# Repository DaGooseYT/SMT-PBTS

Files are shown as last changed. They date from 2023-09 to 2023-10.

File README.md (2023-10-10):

# Surface Mount Technology - Portable Bluetooth Speaker (SMT-PBTS)

<p align="center">
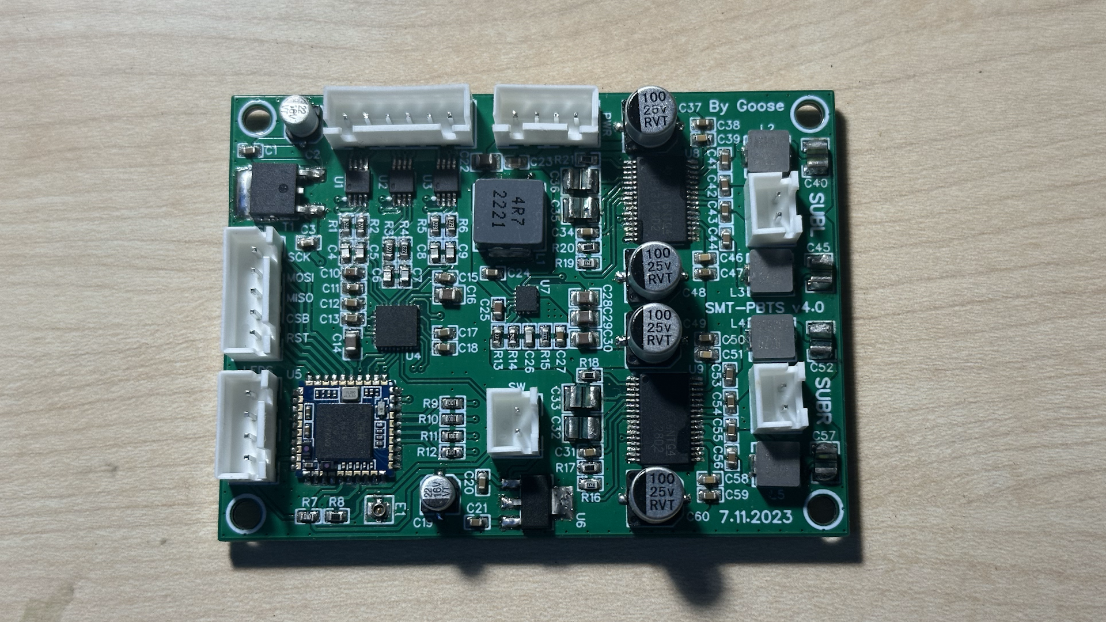
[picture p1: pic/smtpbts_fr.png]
  
</p>

SMT-PBTS is an open source, Hi-Fi Bluetooth speaker PCB designed for the smallest, best sounding portable Bluetooth speaker applications. Just smaller than a credit card, it features multi-channel configurations for an immersive soundstage, a programmable audio DSP, Bluetooth v5.0 technology with external antenna support, 24-bit 192kHz audio support and more.

## Key Features

- Ultra small and compact design; just smaller than a credit card.
- Bluetooth v5.0 specification via Qualcomm’s CSR8675 SoC.
- Connect up to 2 devices simultaneously for shared musical playback.
- Up to 300ft theoretical Bluetooth connectivity range using external antenna.
- Supports nearly every Bluetooth A2DP streaming codec: AAC, SBC, MP3, aptX Classic, aptX-LL, aptX-HD, Faststream  
- High fidelity audio playback with up to 24-bits and 192kHz sample rate support (only using aptX-HD codec).
- Incredible frequency response; 40Hz-22KHz @-3dB (only with suggested drivers and enclosure).
- High efficiency eliminates the need for heatsinks.
- Hybrid amplifier design consisting of Class D amplifiers for the bass drivers and linear Class AB amplifiers for the left, right, and center tweeters.
- Ultra low total harmonic distortion, even at maximum power: ~0.03% THD.
- Ultra low signal to noise ratio: > 108dB
- 35W + 35W onboard Class D amplifiers with 3x1W Class AB amplifiers.
- Uses high-end Panasonic acrylic resin film caps for all audio decoupling filters.

## Schematic

The schematic source for this project is located in `/src`. It is released as an EasyEDA source file. The PNG of the schematic is located in `/pic`.

## PCB

PCB sources are located in `/src`. The sources are EasyEDA PCB design filetypes. PCB gerbers are in the releases.

## BoM
- BoM is available as a .csv file in `/main`
- Only parts and components on the PCB are in the BoM.

## Suggested Enclosure Design

- Outer enclosure demensions are as follows (in): Length: 10.5; Width: 4.25; Depth: 3.5
- Speaker hole diameters (in): Left and right surround speakers: 1.9; two bass drivers: 3.5; center speaker: 1.9
- Connector, Port, and LED hole diameters (in): Power & AUX connectors: 0.5; LEDs: 3/16; Port: 5/8
- It is recommended to use polyfill in the enclosure for better frequency response and dampening. 
- The port of the enslosure is a PVC pipe with a inner diameter of 0.6 inches and is 9.75 inches in length (port tuning is between 40Hz - 45Hz).
- 0.25in thick MDF wood is reccomended for the speaker enclosure build.

## Suggested Drivers

- The two bass drivers are 3.5in in diameter and are manufactured by BH Acoustics (see [datasheet](https://cdn.komachine.com/media/product-catalog/bh-acoustic_84067_fngrun.pdf)). They were salvaged from two Samsung WAM1500 smart speakers. Due two the limited availability of these drivers, it is recomended to use [these drivers](https://www.parts-express.com/dayton-audio-nd90-4-3-1-2-aluminum-cone-full-range-neo-driver-4-ohm--290-208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) as an alternative.
- The center driver is a tweeter. It is rated at 10w 4ohm and was also pulled from a Samsung WAM1500. There is no other public documentation of this driver. [This](https://www.amazon.com/dp/B00LSEVA8I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) driver can be used instead. 
- The two surround tweeters can be found [here](https://a.co/d/8RPXRJ0).

## I/O Connectors
- Power input via 5.5mm power jack. Buy it [here](https://www.parts-express.com/21-x-55mm-dc-coaxial-power-snap-in-jack--090-5030)
- This PCB features Bluetooth v5.0 using the BTM875-E Bluetooth module. The module can be reprogrammed to change the device's name as well as other properties. The programmer module is required because you need to flash the custom firmware onto the chip, which contains the code to drive the AIC3254 slave device. Buy [this](https://www.digikey.com/short/0d7541zq) programmer.

## Other PCB Dependant Componants
- The pre-modulated 4s BMS PCB can be found [here](https://a.co/d/1r3xPFF). I highly suggest swapping out the main IC on this BMS with [this](https://mou.sr/46K4Cju) one for better discharge/overcharge protection and best compatibility with SMT-PBTS.
- Samsung 50E 21700 battery cells can be found [here](https://www.18650batterystore.com/products/samsung-50e) (order 4 for 14.4V configuration)
- Buy lithium-ion battery nickel strips [here](https://a.co/d/34JzgvJ)
- To prevent fire, use 20AWG wires or better for the power connections and TPA3128D2 output connections.
- 16.8V 2A lithium ion battery charger can be found [here](https://a.co/d/1eIaQfp)

## Licensing
This repo is licensed under the GPL v3.0. Any images are licensed under CC BY-SA 3.0.

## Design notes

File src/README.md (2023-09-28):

# Custom firmware configuration guide
SMT-PBTS uses Qualcomm's CSR8675 via the BTM875-E module for Bluetooth radio music streaming. SMT-PBTS requires a specific firmware configuration in order for everything to function as expected. The default firmware I configured myself for my specific application is in the releases. However, your application will be slightly different and therefore it is highly recommended to create your own firmware for the best quality results. This guide will show you the general steps for the correct custom firmware configuration.

## Requirements
- [This](https://www.digikey.com/short/0d7541zq) USB-SPI programmer
- Texas Instruments [PurePath Studio](https://www.ti.com/tool/AICPUREPATH_STUDIO) (proprietary, requires registration)
- CSR867X ADK v4.3.1.5 - software development kit (proprietary, you must find on your own)
- Knowledge of the C programming language
- Knowledge of Qualcomm's xIDE and standard library (I won't discuss its usage in this guide, please read its docs)
- Knowledge of the I2C bus protocol

## Configuring PurePath code
<p align="center">
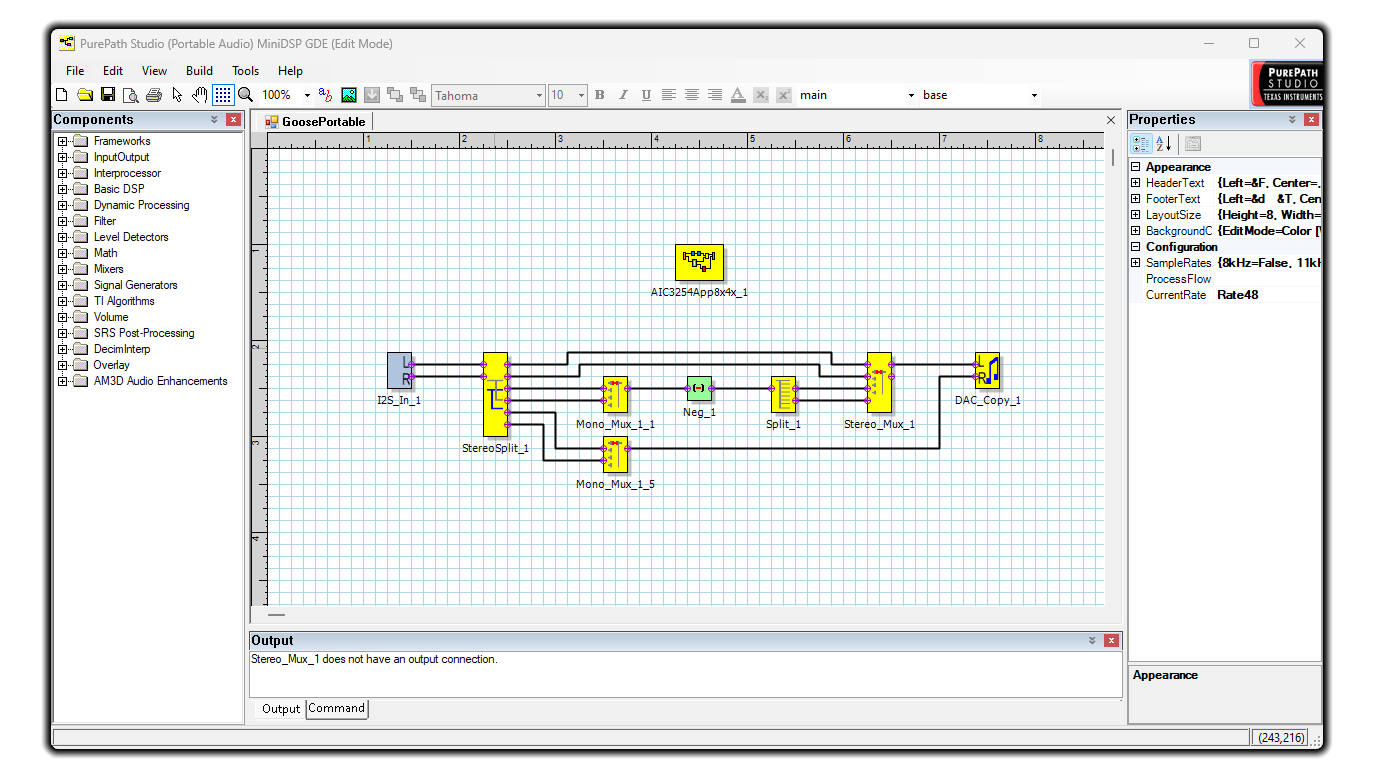
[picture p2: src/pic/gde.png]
  
</p>

Use GDE in the PurePath portable installation to configure the AIC3254 to your liking. The photo above is the configuration used in the firmware I have configured for my specific application. Be sure to use I2S as the input and set the PLL clock to BCLK (this can be found in the AIC3254 app configuration block). The left output channel is for the surround tweeters and the right output is for the center tweeter.

<p align="center">
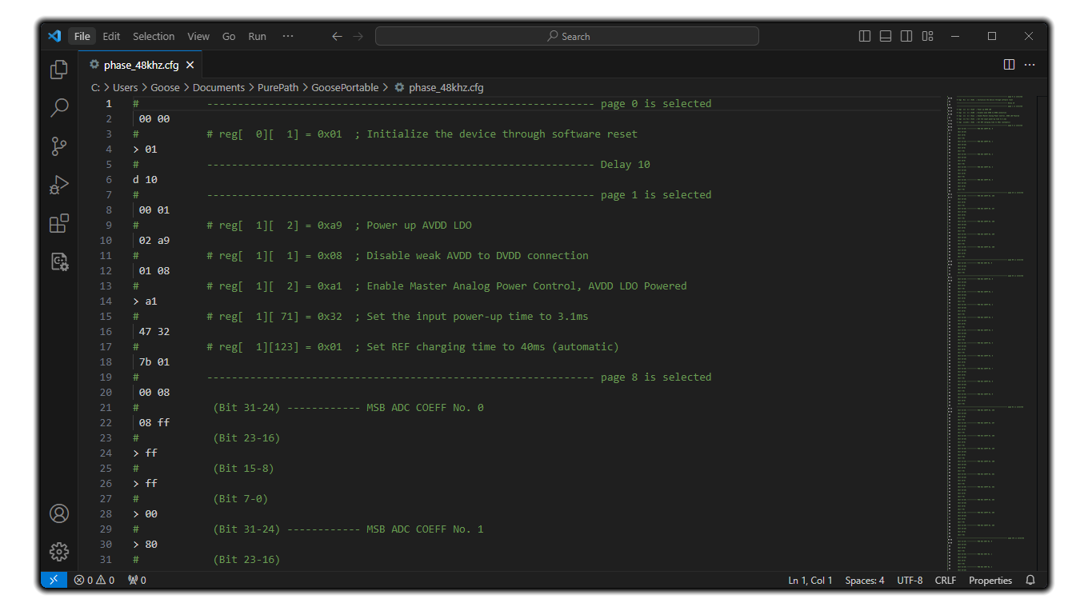
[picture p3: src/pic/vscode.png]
  
</p>

Above is the assembled output code from the GDE configuration. This code must be tweaked in order to be compatible with the CSR8675 firmware that we will build soon. The code lines starting with 'd' must be removed entirely. Delay is not supported in the CSR8675 firmware. The '>' ressembles register incrementation from the previous line which is also not supported and so you must convert these to register values in hex too.

## Adding code to the sink application

<p align="center">
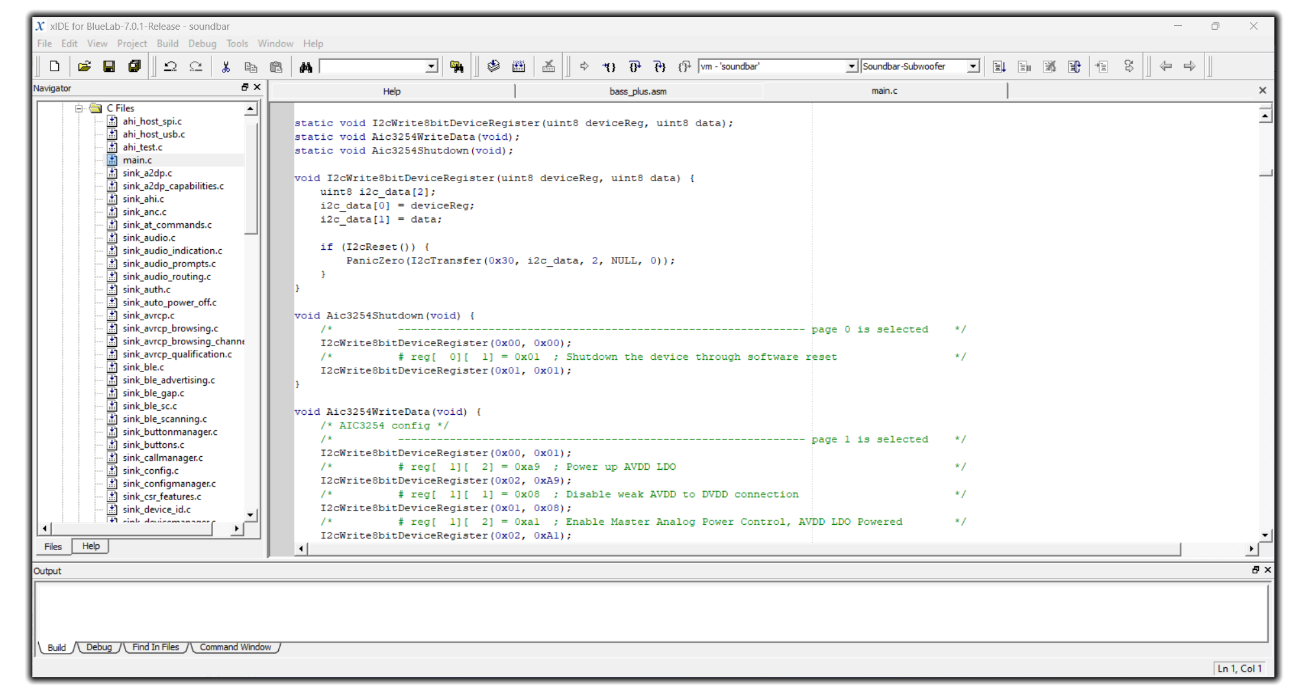
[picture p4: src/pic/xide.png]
  
</p>

Open xIDE in the ADK v4.3.1.5 installation folder and use one of the sample sink app workspaces in the `/apps` directory as a template for your firmware (I recommend the `soundbar.xiw` sample). Also add any of the decoders that you would like (AAC, MP3, aptX-HD, etc.) by going to `Project > Insert project to workspace` and selecting the kalimba project files (in `/a2dp_sink` directory) relating to the codecs that you would like configured.<br />
Create functions and add the code assembled from PurePath GDE into the `main.c` file in the `vm - soundbar` xIDE project. See the `main.c` file in this repository's `/src` folder for a complete example. The example file has the I2C library functions set up and demonstrates the function usage for all relevant code.<br />
Finally, change the configuration properties of the `vm - soundbar` project so that the device is set to CSR8675, the transfer is SPI, and wired audio is enabled (for I2S). You can configure other properties such as subwoofer link, hi-res audio output and more there too, but is completely optional. Be aware though that the CSR8675 on the BTM875-E module only has 16MB of flash memory. Make sure you don't have everything enabled in the project properties as the device will not have enough storage for all of the features! Open the `speaker.mak` file in the `vm -speaker` project and uncomment the A2DP decoder compilation paths for the decoders that you have added to the workspace. 

## Flashing the CSR8675

<p align="center">
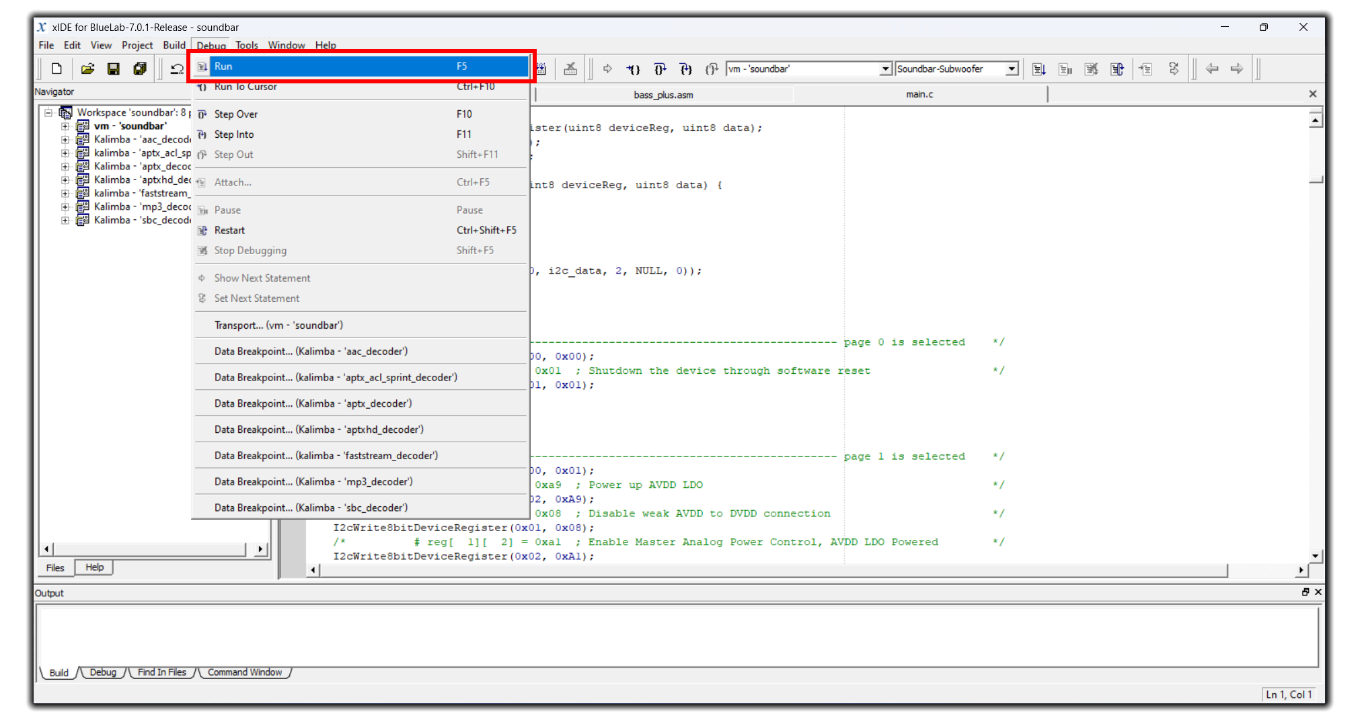
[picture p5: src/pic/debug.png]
  
</p>

Go to `Debug > run` in xIDE after you have configured all of the code and properties. **Make sure the BTM875-E and the USB-SPI module is connected to your computer and the CSR8675 chip is erased (use BlueFlash.exe in the ADK installtion folder), else it will fail.** It could take several minutes to compile and assemble all of the code. After all compilation is complete, the firmware will automatically flash itself to the CSR8675 device. 

## Persistent store keys configuration

<p align="center">
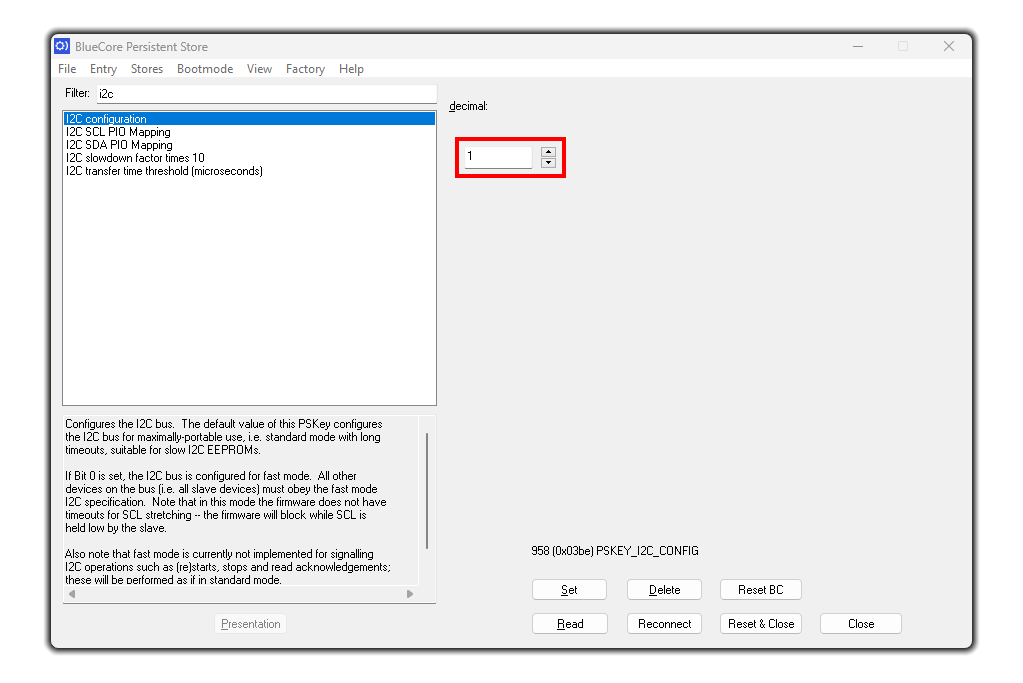
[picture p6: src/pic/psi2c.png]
  
</p>

Open PSTool and merge the `sink_system_csr8675.psr` default file located in the `/configurations` folder of your sink project directory.<br />
Search i2c in the search box and change the I2C configuration key value to 1 as shown above. This is for I2C fast mode enable.

<p align="center">
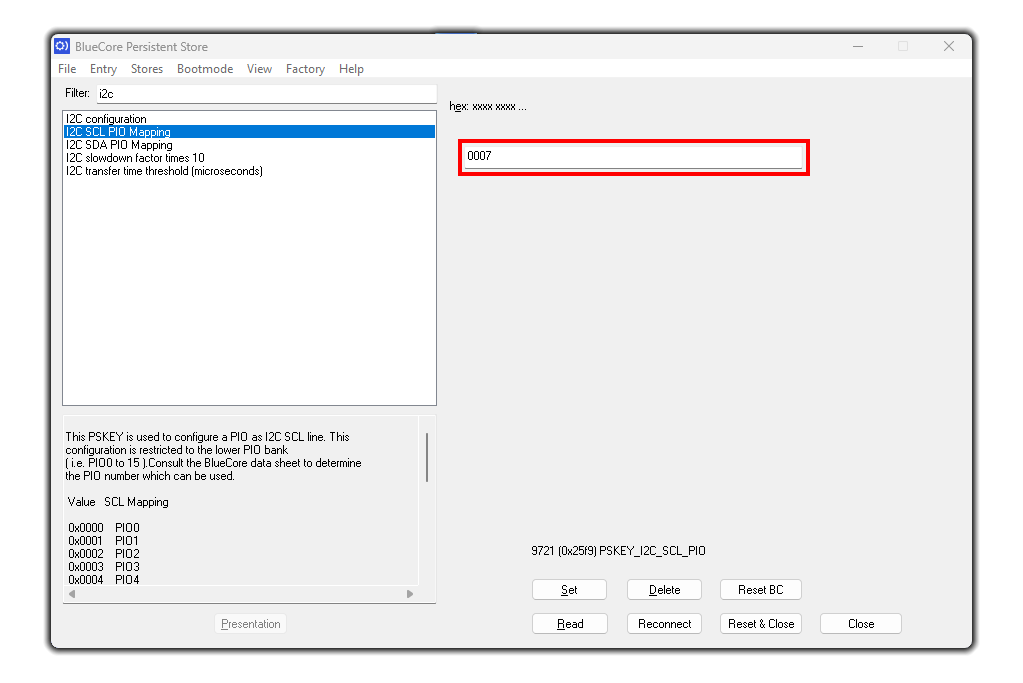
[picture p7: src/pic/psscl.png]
  
</p>

Set the SCL pin to 0007 as shown above for PIO7 according to the hardware configuration on the SMT-PBTS PCB.

<p align="center">
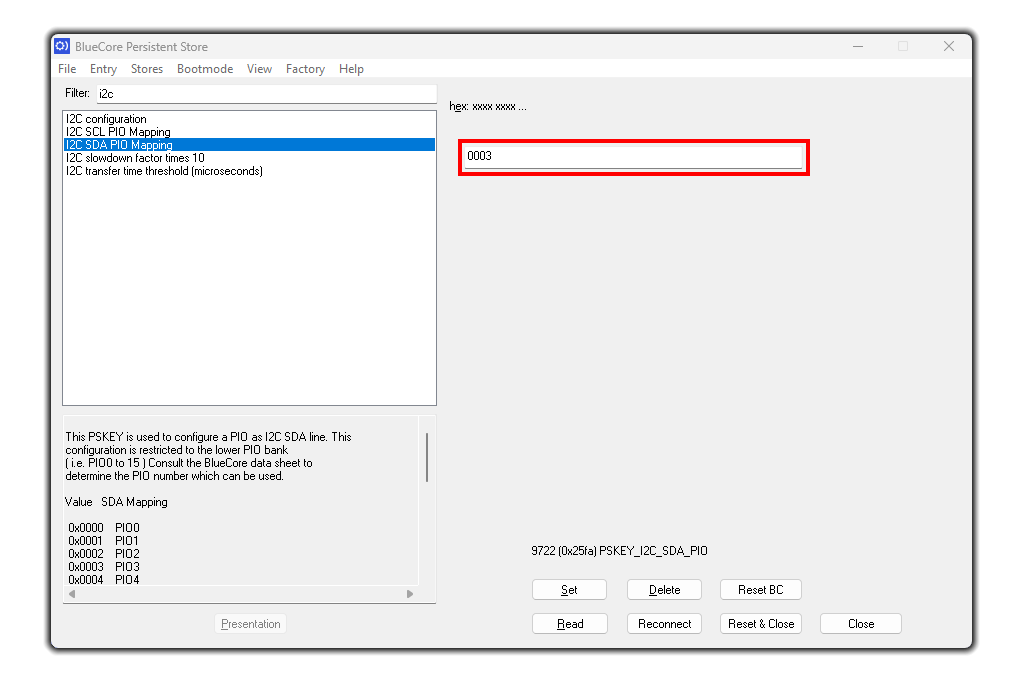
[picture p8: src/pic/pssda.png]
  
</p>

Set the SDA pin to 0003 as shown above for PIO3 according to the hardware configuration on the SMT-PBTS PCB.<br />
Now switch off the MFB switch on the SMT-PBTS PCB and then unplug the battery. Plug back in the battery connector and then switch on the MFB switch to turn on the module.

## ADK configuration settings

<p align="center">
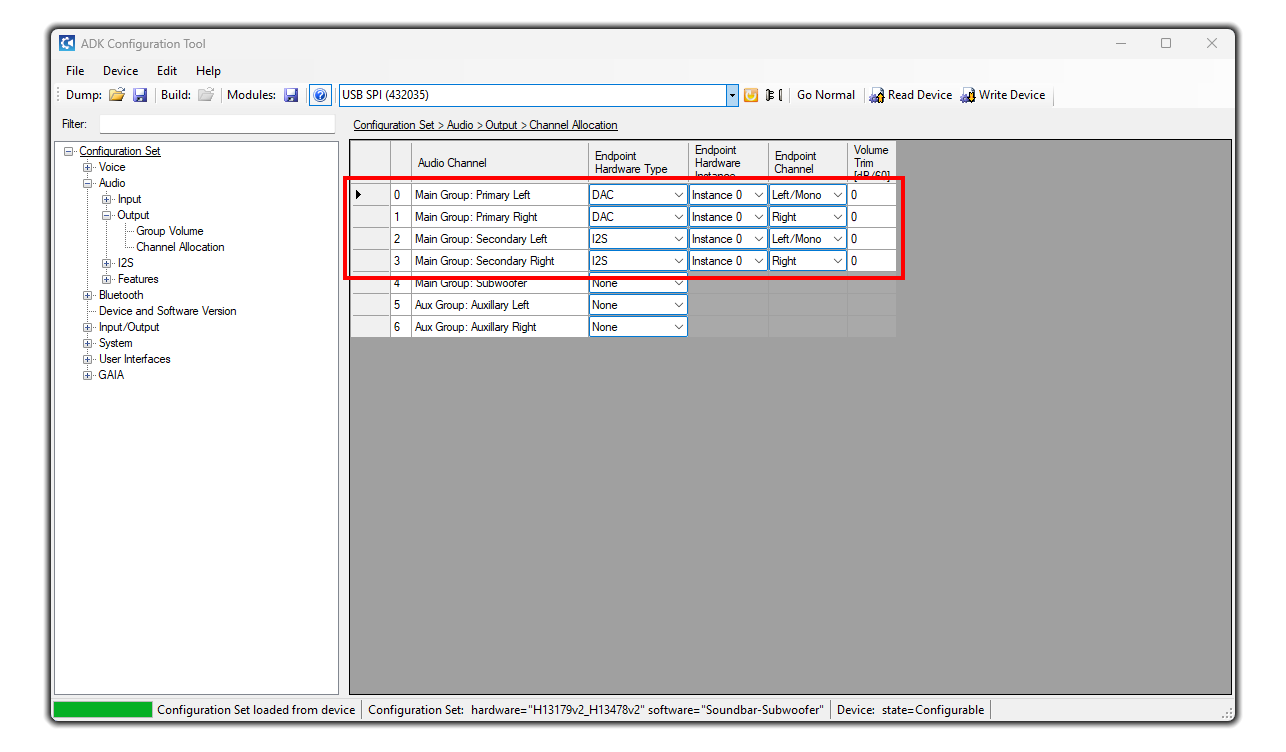
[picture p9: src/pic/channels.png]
  
</p>

Now open the ADK Configuration Tool located in the ADK v4.3.1.5 installation folder. With the USB-SPI module still connected to the SMT-PBTS PCB, select the USB-SPI in the connection drop-down menu and then select the `Go Configurable` button. Once the device configurations loads, select the `Read device` button.<br />
Go to `Audio > Output > Channel Allocation` in the menu and set the configuration to the picture as shown above.

<p align="center">
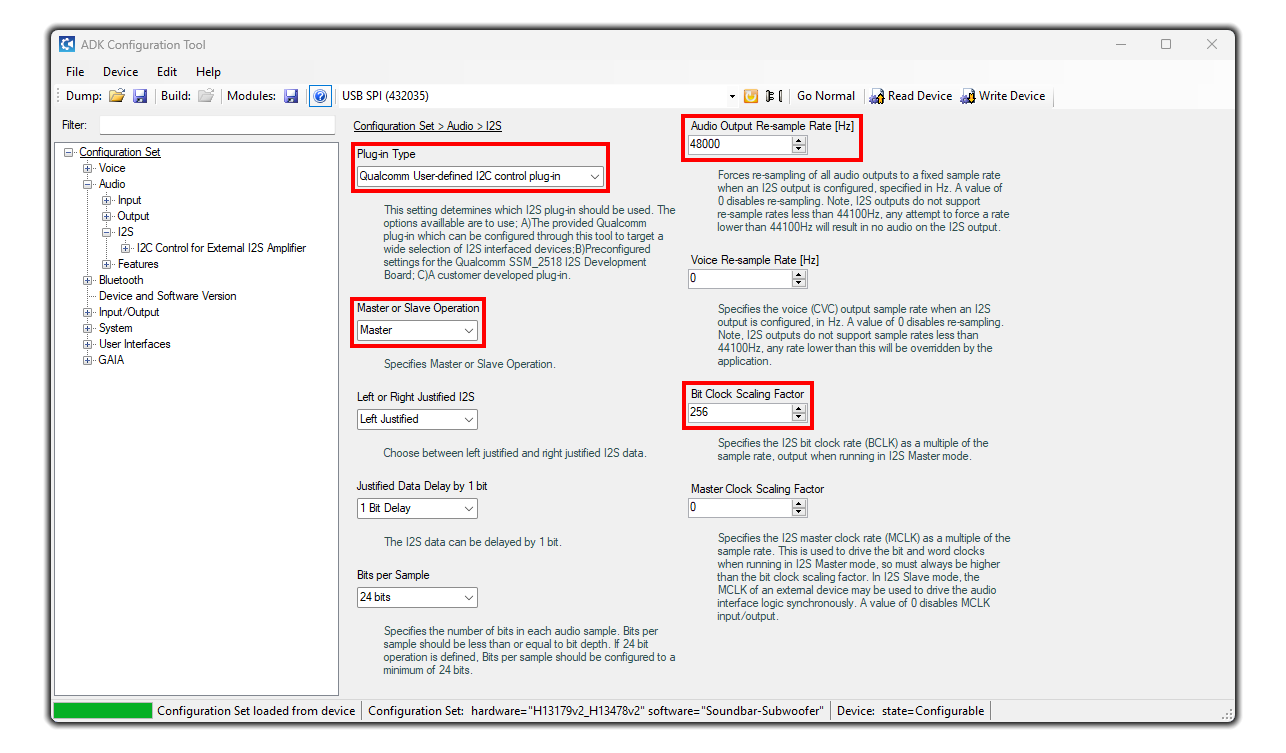
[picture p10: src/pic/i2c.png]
  
</p>

Now go to `Audio > I2S` and set the configurations to the picture as shown above.

<p align="center">
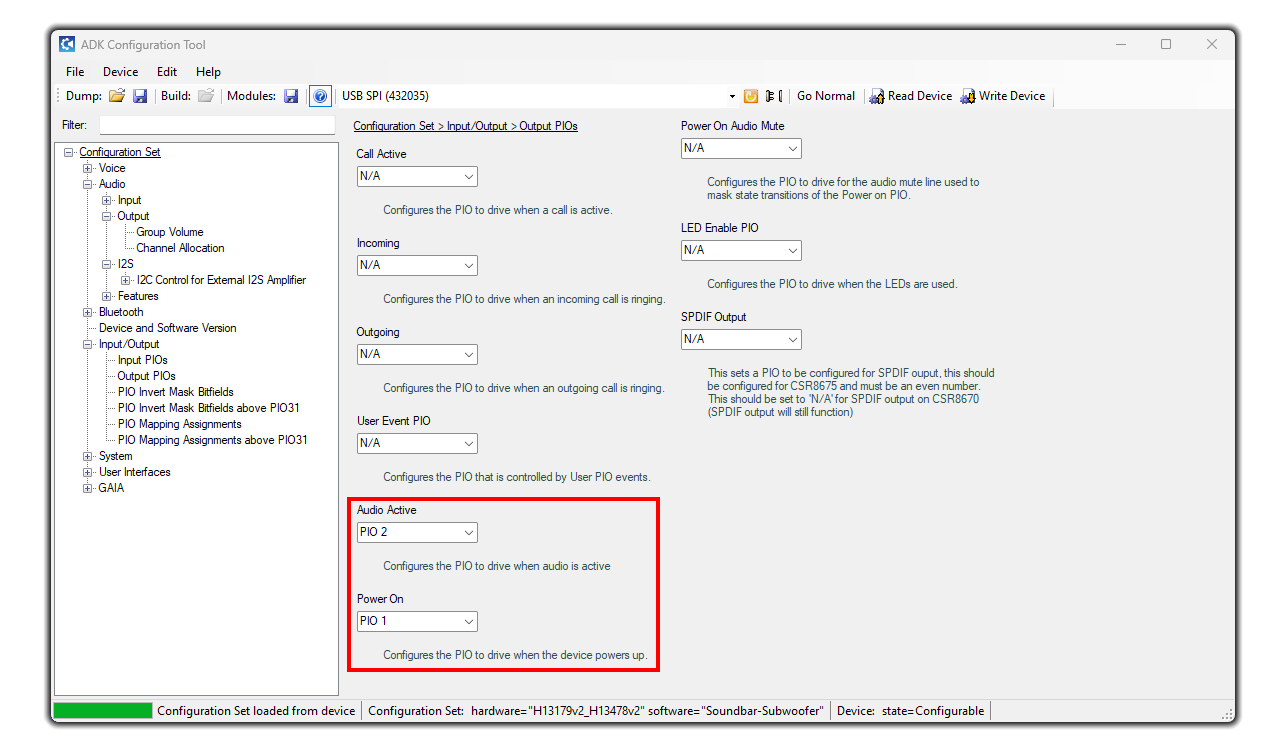
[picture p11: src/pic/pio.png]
  
</p>

Lastly, go to `Input/Output > Output PIOs` and set the configuration to the picture as shown above in accordance to the hardware configuration on the SMT-PBTS PCB. In the `PIO Invert Mask Bitfields` menu, also invert PIO2 by selecting the checkbox next to it. You may configure other settings, such as changing the LED sequence and start-up tones in the other menus. Once finished, select `Write device` to add the configuration to the CSR8675 and then select `Go normal` to make the module run normally.

## DSP configuration

<p align="center">
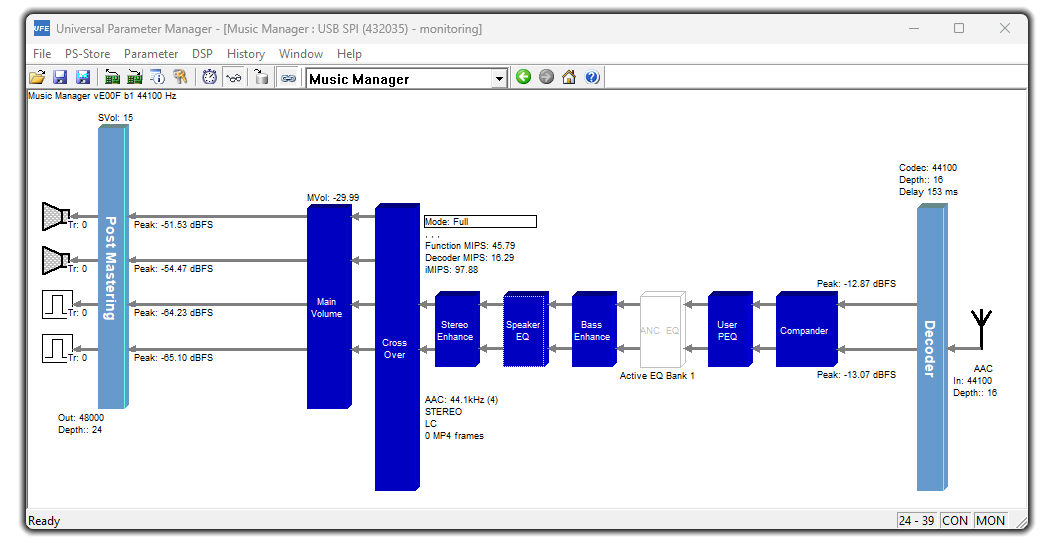
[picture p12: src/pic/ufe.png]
  
</p>

At last, open UniversalFrontEnd in the ADK v4.3.1.5 installation directory and then select `music manager` in the menu. Select your USB-SPI device in the menu. **Make sure music is playing before you connect else you will get an error. Make sure music plays for the rest of this part of the guide to prevent problems.** Once connected, select the sunglasses-looking icon on the top of the program to monitor the DSP memory in real-time. Your screen should look like the one pictured above. To apply changes that you make to all decoders, select the `Decoder` block and then select all relevent checkboxes.

<p align="center">
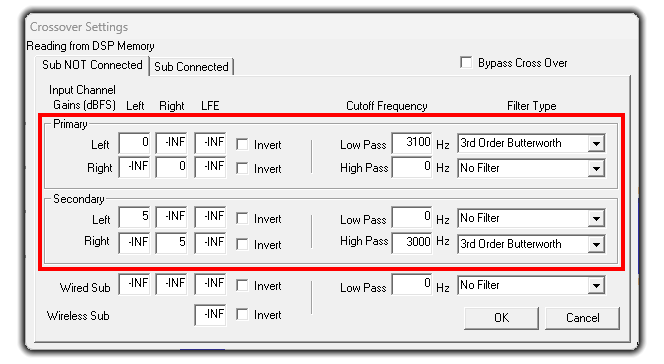
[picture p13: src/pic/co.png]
  
</p>

Select the `Cross over` block to see the crossover menu and configure it to what you see in the photo above. Select OK to apply the changes.

<p align="center">
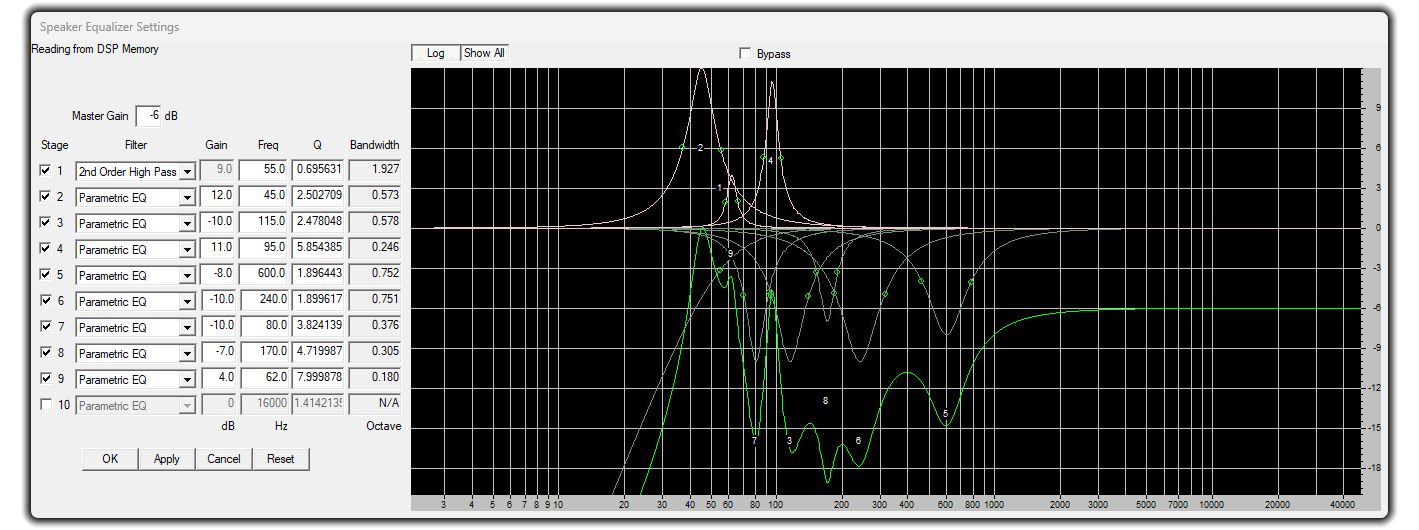
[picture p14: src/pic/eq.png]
  
</p>

Select the `Speaker EQ` block to see the DSP equilizer. Set this accoding to your liking. DSP EQ tuning can take a lot of time for the perfect configuration so be sure to have patience when testing different EQ configs. The 10th EQ band for some reason doesn't work and if you select the checkbox the app will crash. The DSP EQ config shown in the photo above is the one I made for my application. Yours will most likely look very different!<br /><br />
This concludes the firmware configuration guide. I did not provide much details as far as the usage of these tools because I expect that you already know how to use them. If you don't, please refer to the documentation for each of them. **Please refrain from opening issues regarding usage of the tools; I won't hold your hand through each little step not mentioned in this guide.**

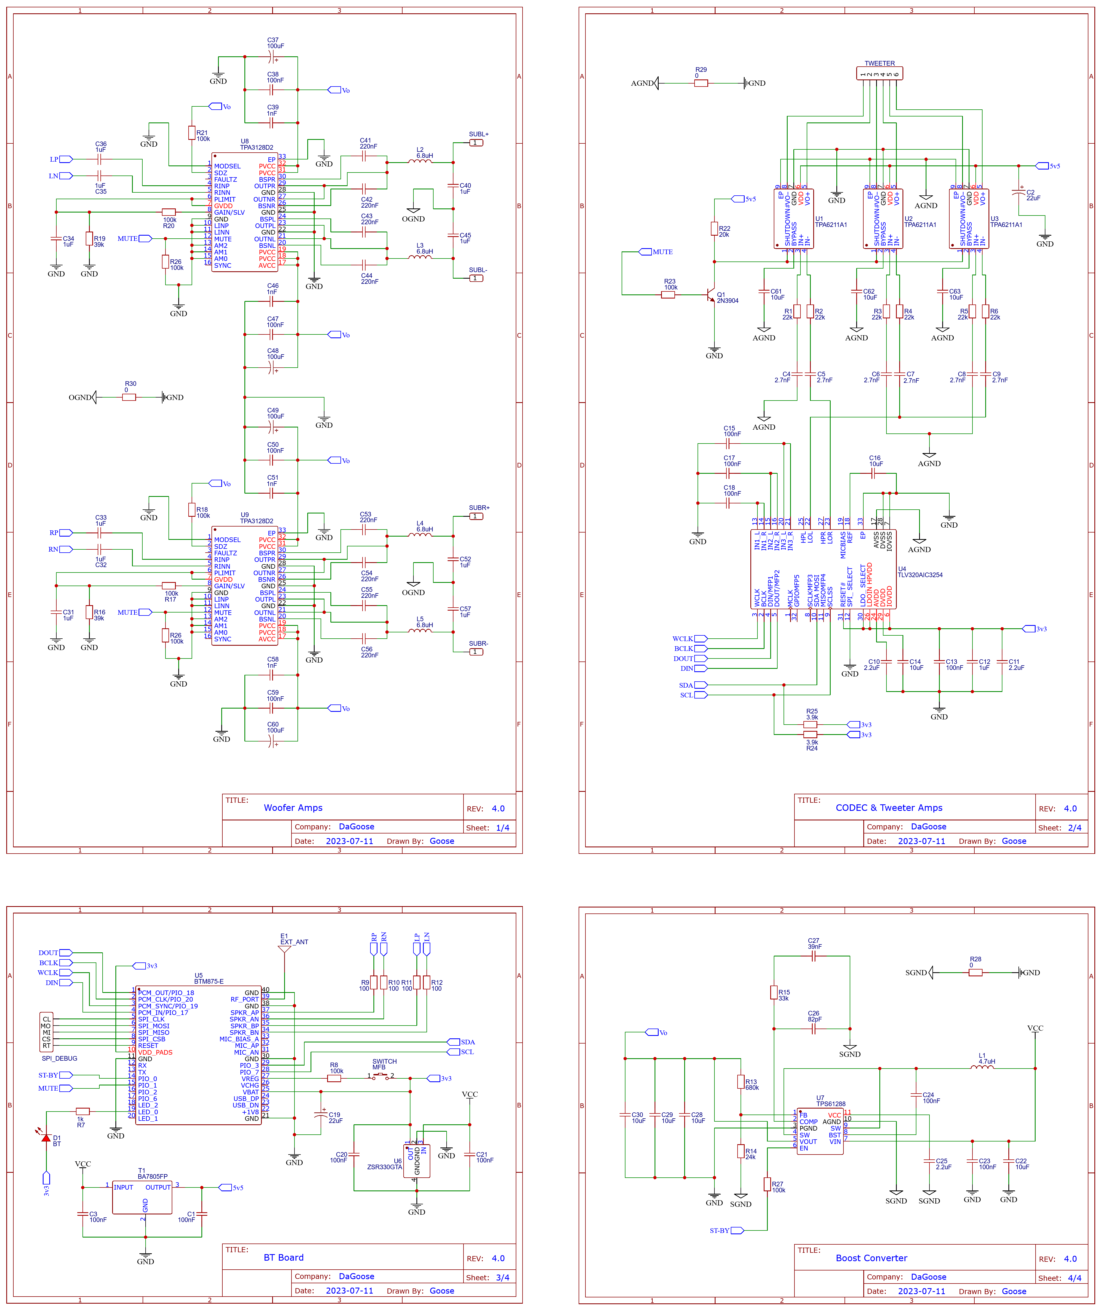
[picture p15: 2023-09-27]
pic/SCH_SMT-PBTS_v4.0.png

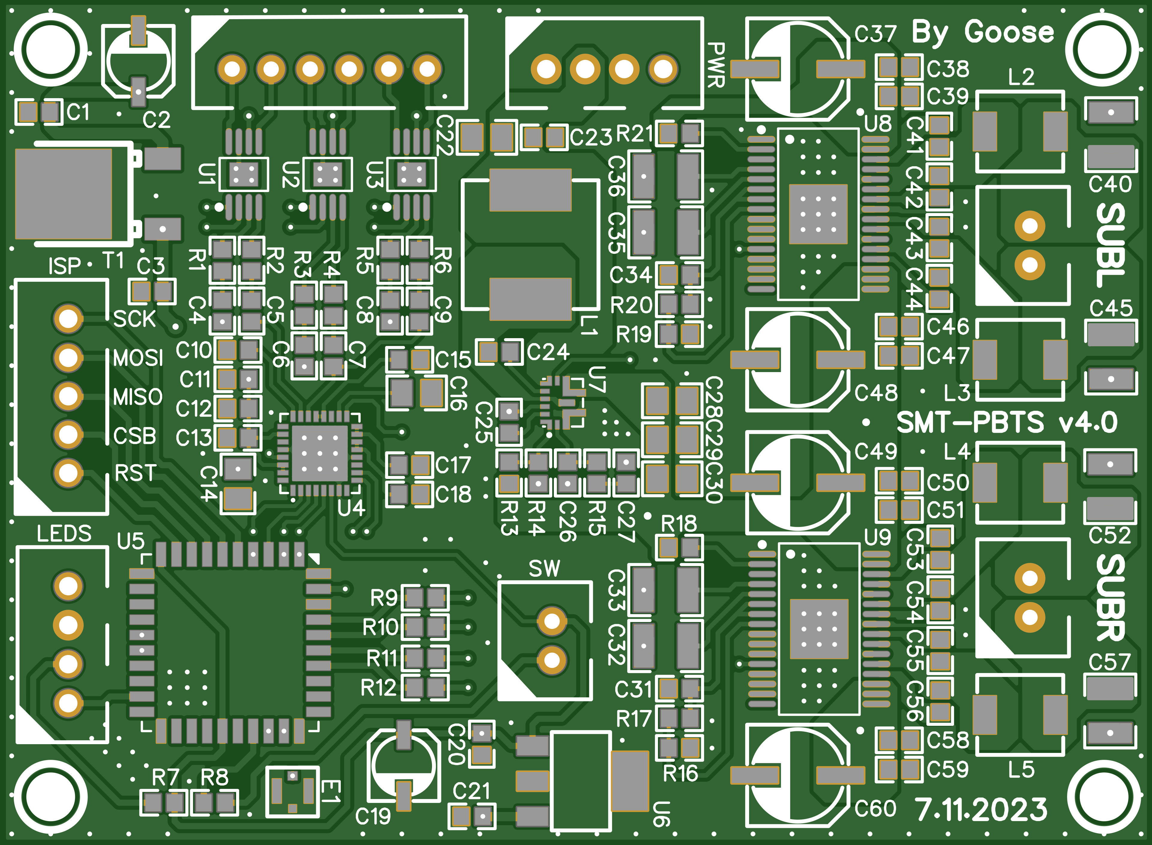
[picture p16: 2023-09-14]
pic/top_layer.png

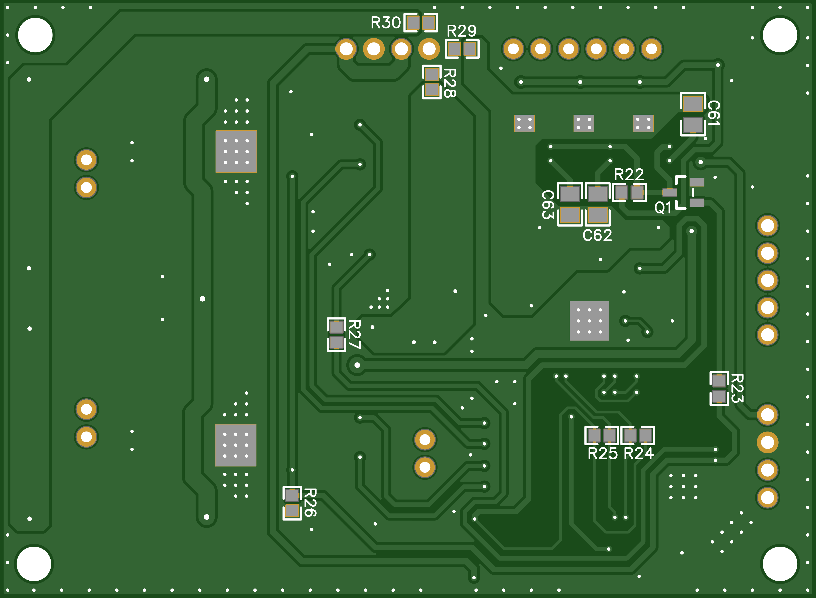
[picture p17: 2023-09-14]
pic/bottom_layer.png

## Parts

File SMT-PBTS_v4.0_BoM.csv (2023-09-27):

Componant | Description | Count | Manufacturer | Manufacturer Part Number | Comment
C1, C3, C13, C15, C17, C18, C20, C21, C23, C24, C38, C47, C50, C59 | 100nF, 25V, 0603, X7R, ±20% | 14 | - | - | Ceramic
C2, C19 | 22uF, 16V, 5.5mm x 4.5mm, ±20% | 2 | - | - | Electrolytic
C4, C5, C6, C7, C8, C9 | 2.7nF, 16V, 0603, ±2% | 6 | Panasonic | ECH-U1C272GX5 | Acrylic resin film
C10, C11, C25 | 2.2uF, 16V, 0603, X7R, ±20% | 3 | - | - | Ceramic
C12, C31, C34 | 1uF, 16V, 0603, X7R, ±20% | 3 | - | - | Ceramic
C14, C16, C22, C28, C29, C30, C61, C62, C63 | 10uF, 16V, 0804, X7R, ±20% | 9 | - | - | Ceramic
C26 | 82pF, 16V, 0603, X7R, ±20% | 1 | - | - | Ceramic
C27 | 39pF, 16V, 0603, X7R, ±20% | 1 | - | - | Ceramic
C32, C33, C35, C36, C40, C45, C52, C57 | 1uF, 16V, 1210, ±20% | 8 | Panasonic | ECP-U1C105MA5 | Acrylic resin film
C37, C48, C49, C60 | 100uF, 25V, ±20% | 4 | - | - | Electrolytic
C39, C46, C51, C58 | 1nF, 25V, 0603, X7R, ±20% | 4 | - | - | Ceramic
C41, C42, C43, C44, C53, C54, C55, C56 | 220nF, 16V, 0603, X7R, ±20% | 8 | - | - | Ceramic
E1 | MHF4 connector | 1 | Linx Technologies | CONMHF4-SMD-G-T | -
L1 | 4.7uH, 8.5A power inductor | 2 | Bourns | SRP8540A-4R7M | Must have a current limit no less than 8A
L2, L3, L4, L5 | 6.8uH, 3.3A power inductor | 4 | Eaton | HCM1A0503V2-6R8-R | Must have a current limit no less than 3A
R1, R2, R3, R4, R5, R6 | 22KΩ, 0603, ±1% | 6 | - | - | Film
R7 | 1KΩ, 0603, ±1% | 1 | - | - | Film
R8, R17, R18, R20, R21, R26, R27 | 100KΩ, 0603, ±1% | 7 | - | - | Film
R9, R10, R11, R12 | 10Ω, 0603, ±1% | 4 | - | - | Film
R13 | 680KΩ, 0603, ±1% | 1 | - | - | Film
R14 | 24KΩ, 0603, ±1% | 1 | - | - | Film
R15 | 33KΩ, 0603, ±1% | 1 | - | - | Film
R16, R19 | 39KΩ, 0603, ±1% | 2 | - | - | Film
R22, R23 | 20KΩ, 0603, ±1% | 2 | - | - | Film
R24, R25 | 3.9KΩ, 0603, ±1% | 2 | - | - | Film
R28, R29, R30 | 0Ω, 0603, ±1% | 3 | - | - | Film
T1 | Linear voltage regulator, 5V 1A | 1 | ROHM Semiconductor | BA7805FP-E2 | -
U1, U2, U3 | 3.1W mono Class AB audio amplifier | 3 | Texas Instruments | TPA6211A1TDGNRQ1 | Single ended inputs
U4 | Audio CODEC with embedded miniDSP | 1 | Texas Instruments | TLV320AIC3254IRHBR | Requires TI PurePath for software configuration
U5 | Miniture CSR8675 Bluetooth module | 1 | 天嘉润科技 | SJR-BTM875-E | Requires custom firmware configuration
U6 | Linear voltage regulator, 3.3V 200mA | 1 | Diodes Incorporated | ZSR330GTA | OBSOLETE - 9/27/2023
U7 | Switching boost converter regulator | 1 | Texas Instruments | TPS61288LRQQR | Output: 17.5V 5A
U8, U9 | Dual 30W audio power amplifier / 60W mono | 2 | Texas Instruments | TPA3128D2DAPR | Used in PBTL mode
SW, SUBL, SUBR | 1x2 2.54mm socket | 3 | JST | XH2.54-2p | -
LEDS, PWR | 1x4 2.54mm socket | 2 | JST | XH2.54-4p | -
ISP | 1x5 2.54mm socket | 1 | JST | XH2.54-5p | -

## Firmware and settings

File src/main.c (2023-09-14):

/****************************************************************************
 * Copyright (C) 2023 DaGoose
 *
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
 * You should have received a copy of the GNU Affero General Public License
 * along with this program.  If not, see <http://www.gnu.org/licenses/>.
 ****************************************************************************/

/* THIS IS NOT THE FULL FIRMWARE CODE! THIS CODE ONLY DEMONSTRATES USAGE FOR AIC3254 IN THIS APPLICATION */

#include <stream.h>
#include <sink.h>
#include <source.h>
#include <string.h>
#include <panic.h>
#include <message.h>
#include <stdlib.h>
#include <i2c.h>

static void I2cWrite8bitDeviceRegister(uint8 deviceReg, uint8 data);
static void Aic3254WriteData(void);
static void Aic3254Shutdown(void);

void I2cWrite8bitDeviceRegister(uint8 deviceReg, uint8 data) {
    uint8 i2c_data[2];
    i2c_data[0] = deviceReg;
    i2c_data[1] = data;

    /* 0011000 slave address */
    if (I2cReset()) {
        PanicZero(I2cTransfer(0x30, i2c_data, 2, NULL, 0));
    }
}

void Aic3254Shutdown(void) {
    /*		    --------------------------------------------------------------- page 0 is selected    */
    I2cWrite8bitDeviceRegister(0x00, 0x00);
    /*			# reg[  0][  1] = 0x01	; shutdown the device through software reset                  */
    I2cWrite8bitDeviceRegister(0x01, 0x01);
}

/* AIC3254 config */
void Aic3254WriteData(void) {
    /*			--------------------------------------------------------------- page 1 is selected    */
    I2cWrite8bitDeviceRegister(0x00, 0x01);
    /*			# reg[  1][  2] = 0xa9	; power up AVDD LDO                                           */
    I2cWrite8bitDeviceRegister(0x02, 0xA9);
    /*			# reg[  1][  1] = 0x08	; disable weak AVDD to DVDD connection                        */
    I2cWrite8bitDeviceRegister(0x01, 0x08);
    /*			# reg[  1][  2] = 0xa1	; enable Master Analog Power Control, AVDD LDO Powered        */
    I2cWrite8bitDeviceRegister(0x02, 0xA1);
    /*			# reg[  1][ 71] = 0x32	; set the input power-up time to 3.1ms                        */
    I2cWrite8bitDeviceRegister(0x47, 0x32);
    /*			# reg[  1][123] = 0x01	; set REF charging time to 40ms (automatic)                   */
    I2cWrite8bitDeviceRegister(0x7B, 0x01);
    /*			--------------------------------------------------------------- page 44 is selected   */
    I2cWrite8bitDeviceRegister(0x00, 0x2C);
    /*			 (Bit 31-24) ------------ MSB DAC COEFF No. 0                                         */
    I2cWrite8bitDeviceRegister(0x08, 0x00);
    /*			 (Bit 23-16)                                                                          */
    I2cWrite8bitDeviceRegister(0x09, 0x00);
    /*			 (Bit 15-8)                                                                           */
    I2cWrite8bitDeviceRegister(0x0A, 0x01);
    /*			 (Bit 7-0)                                                                            */
    I2cWrite8bitDeviceRegister(0x0B, 0x00);
    /*			 (Bit 31-24) ------------ MSB DAC COEFF No. 1                                         */
    I2cWrite8bitDeviceRegister(0x0C, 0xFF);
    /*			 (Bit 23-16)                                                                          */
    I2cWrite8bitDeviceRegister(0x0D, 0xFF);
    /*			 (Bit 15-8)                                                                           */
    I2cWrite8bitDeviceRegister(0x0E, 0xFF);
    /*			 (Bit 7-0)                                                                            */
    I2cWrite8bitDeviceRegister(0x0F, 0x00);
    /*			 (Bit 31-24) ------------ MSB DAC COEFF No. 2                                         */
    I2cWrite8bitDeviceRegister(0x10, 0x80);
    /*			 (Bit 23-16)                                                                          */
    I2cWrite8bitDeviceRegister(0x11, 0x00);
    /*			 (Bit 15-8)                                                                           */
    I2cWrite8bitDeviceRegister(0x12, 0x00);
    /*			 (Bit 7-0)                                                                            */
    I2cWrite8bitDeviceRegister(0x13, 0x00);
    /*			 (Bit 31-24) ------------ MSB DAC COEFF No. 3                                         */
    I2cWrite8bitDeviceRegister(0x14, 0x40);
    /*			 (Bit 23-16)                                                                          */
    I2cWrite8bitDeviceRegister(0x15, 0x00);
    /*			 (Bit 15-8)                                                                           */
    I2cWrite8bitDeviceRegister(0x16, 0x00);
    /*			 (Bit 7-0)                                                                            */
    I2cWrite8bitDeviceRegister(0x17, 0x00);
    /*			 (Bit 31-24) ------------ MSB DAC COEFF No. 4                                         */
    I2cWrite8bitDeviceRegister(0x18, 0x7F);
    /*			 (Bit 23-16)                                                                          */
    I2cWrite8bitDeviceRegister(0x19, 0xFF);
    /*			 (Bit 15-8)                                                                           */
    I2cWrite8bitDeviceRegister(0x1A, 0xFF);
    /*			 (Bit 7-0)                                                                            */
    I2cWrite8bitDeviceRegister(0x1B, 0x00);
    /*			 (Bit 31-24) ------------ MSB DAC COEFF No. 5                                         */
    I2cWrite8bitDeviceRegister(0x1C, 0x00);
    /*			 (Bit 23-16)                                                                          */
    I2cWrite8bitDeviceRegister(0x1D, 0x00);
    /*			 (Bit 15-8)                                                                           */
    I2cWrite8bitDeviceRegister(0x1E, 0x00);
    /*			 (Bit 7-0)                                                                            */
    I2cWrite8bitDeviceRegister(0x1F, 0x00);
    /*			 (Bit 31-24) ------------ MSB DAC COEFF No. 15                                        */
    I2cWrite8bitDeviceRegister(0x44, 0x00);
    /*			 (Bit 23-16)                                                                          */
    I2cWrite8bitDeviceRegister(0x45, 0x00);
    /*			 (Bit 15-8)                                                                           */
    I2cWrite8bitDeviceRegister(0x46, 0x01);
    /*			 (Bit 7-0)                                                                            */
    I2cWrite8bitDeviceRegister(0x47, 0x00);
    /*			 (Bit 31-24) ------------ MSB DAC COEFF No. 16                                        */
    I2cWrite8bitDeviceRegister(0x48, 0x00);
    /*			 (Bit 23-16)                                                                          */
    I2cWrite8bitDeviceRegister(0x49, 0x00);
    /*			 (Bit 15-8)                                                                           */
    I2cWrite8bitDeviceRegister(0x4A, 0x01);
    /*			 (Bit 7-0)                                                                            */
    I2cWrite8bitDeviceRegister(0x4B, 0x00);
    /*			--------------------------------------------------------------- page 62 is selected   */
    I2cWrite8bitDeviceRegister(0x00, 0x3E);
    /*			 (Bit 31-24) ------------ MSB DAC COEFF No. 256                                       */
    I2cWrite8bitDeviceRegister(0x08, 0x00);
    /*			 (Bit 23-16)                                                                          */
    I2cWrite8bitDeviceRegister(0x09, 0x00);
    /*			 (Bit 15-8)                                                                           */
    I2cWrite8bitDeviceRegister(0x0A, 0x01);
    /*			 (Bit 7-0)                                                                            */
    I2cWrite8bitDeviceRegister(0x0B, 0x00);
    /*			 (Bit 31-24) ------------ MSB DAC COEFF No. 257                                       */
    I2cWrite8bitDeviceRegister(0x0C, 0xFF);
    /*			 (Bit 23-16)                                                                          */
    I2cWrite8bitDeviceRegister(0x0D, 0xFF);
    /*			 (Bit 15-8)                                                                           */
    I2cWrite8bitDeviceRegister(0x0E, 0xFF);
    /*			 (Bit 7-0)                                                                            */
    I2cWrite8bitDeviceRegister(0x0F, 0x00);
    /*			 (Bit 31-24) ------------ MSB DAC COEFF No. 258                                       */
    I2cWrite8bitDeviceRegister(0x10, 0x80);
    /*			 (Bit 23-16)                                                                          */
    I2cWrite8bitDeviceRegister(0x11, 0x00);
    /*			 (Bit 15-8)                                                                           */
    I2cWrite8bitDeviceRegister(0x12, 0x00);
    /*			 (Bit 7-0)                                                                            */
    I2cWrite8bitDeviceRegister(0x13, 0x00);
    /*			 (Bit 31-24) ------------ MSB DAC COEFF No. 259                                       */
    I2cWrite8bitDeviceRegister(0x14, 0x40);
    /*			 (Bit 23-16)                                                                          */
    I2cWrite8bitDeviceRegister(0x15, 0x00);
    /*			 (Bit 15-8)                                                                           */
    I2cWrite8bitDeviceRegister(0x16, 0x00);
    /*			 (Bit 7-0)                                                                            */
    I2cWrite8bitDeviceRegister(0x17, 0x00);
    /*			 (Bit 31-24) ------------ MSB DAC COEFF No. 260                                       */
    I2cWrite8bitDeviceRegister(0x18, 0x7F);
    /*			 (Bit 23-16)                                                                          */
    I2cWrite8bitDeviceRegister(0x19, 0xFF);
    /*			 (Bit 15-8)                                                                           */
    I2cWrite8bitDeviceRegister(0x1A, 0xFF);
    /*			 (Bit 7-0)                                                                            */
    I2cWrite8bitDeviceRegister(0x1B, 0x00);
    /*			 (Bit 31-24) ------------ MSB DAC COEFF No. 261                                       */
    I2cWrite8bitDeviceRegister(0x1C, 0x00);
    /*			 (Bit 23-16)                                                                          */
    I2cWrite8bitDeviceRegister(0x1D, 0x00);
    /*			 (Bit 15-8)                                                                           */
    I2cWrite8bitDeviceRegister(0x1E, 0x00);
    /*			 (Bit 7-0)                                                                            */
    I2cWrite8bitDeviceRegister(0x1F, 0x00);
    /*			 (Bit 31-24) ------------ MSB DAC COEFF No. 271                                       */
    I2cWrite8bitDeviceRegister(0x44, 0x00);
    /*			 (Bit 23-16)                                                                          */
    I2cWrite8bitDeviceRegister(0x45, 0x00);
    /*			 (Bit 15-8)                                                                           */
    I2cWrite8bitDeviceRegister(0x46, 0x01);
    /*			 (Bit 7-0)                                                                            */
    I2cWrite8bitDeviceRegister(0x47, 0x00);
    /*			 (Bit 31-24) ------------ MSB DAC COEFF No. 272                                       */
    I2cWrite8bitDeviceRegister(0x48, 0x00);
    /*			 (Bit 23-16)                                                                          */
    I2cWrite8bitDeviceRegister(0x49, 0x00);
    /*			 (Bit 15-8)                                                                           */
    I2cWrite8bitDeviceRegister(0x4A, 0x01);
    /*			 (Bit 7-0)                                                                            */
    I2cWrite8bitDeviceRegister(0x4B, 0x00);
    /*			--------------------------------------------------------------- page 152 is selected  */
    I2cWrite8bitDeviceRegister(0x00, 0x98);
    /*			 (Bit 31-24) ------------ MSB DAC INST No. 0                                          */
    I2cWrite8bitDeviceRegister(0x08, 0x00);
    /*			 (Bit 23-16)                                                                          */
    I2cWrite8bitDeviceRegister(0x09, 0x00);
    /*			 (Bit 15-8)                                                                           */
    I2cWrite8bitDeviceRegister(0x0A, 0x00);
    /*			 (Bit 7-0)                                                                            */
    I2cWrite8bitDeviceRegister(0x0B, 0x00);
    /*			 (Bit 31-24) ------------ MSB DAC INST No. 1                                          */
    I2cWrite8bitDeviceRegister(0x0C, 0x00);
    /*			 (Bit 23-16)                                                                          */
    I2cWrite8bitDeviceRegister(0x0D, 0x00);
    /*			 (Bit 15-8)                                                                           */
    I2cWrite8bitDeviceRegister(0x0E, 0x00);
    /*			 (Bit 7-0)                                                                            */
    I2cWrite8bitDeviceRegister(0x0F, 0x00);
    /*			 (Bit 31-24) ------------ MSB DAC INST No. 2                                          */
    I2cWrite8bitDeviceRegister(0x10, 0x08);
    /*			 (Bit 23-16)                                                                          */
    I2cWrite8bitDeviceRegister(0x11, 0x00);
    /*			 (Bit 15-8)                                                                           */
    I2cWrite8bitDeviceRegister(0x12, 0x00);
    /*			 (Bit 7-0)                                                                            */
    I2cWrite8bitDeviceRegister(0x13, 0x00);
    /*			 (Bit 31-24) ------------ MSB DAC INST No. 3                                          */
    I2cWrite8bitDeviceRegister(0x14, 0x08);
    /*			 (Bit 23-16)                                                                          */
    I2cWrite8bitDeviceRegister(0x15, 0x04);
    /*			 (Bit 15-8)                                                                           */
    I2cWrite8bitDeviceRegister(0x16, 0x01);
    /*			 (Bit 7-0)                                                                            */
    I2cWrite8bitDeviceRegister(0x17, 0x00);
    /*			 (Bit 31-24) ------------ MSB DAC INST No. 4                                          */
    I2cWrite8bitDeviceRegister(0x18, 0x30);
    /*			 (Bit 23-16)                                                                          */
    I2cWrite8bitDeviceRegister(0x19, 0x0C);
    /*			 (Bit 15-8)                                                                           */
    I2cWrite8bitDeviceRegister(0x1A, 0x00);
    /*			 (Bit 7-0)                                                                            */
    I2cWrite8bitDeviceRegister(0x1B, 0x00);
    /*			 (Bit 31-24) ------------ MSB DAC INST No. 5                                          */
    I2cWrite8bitDeviceRegister(0x1C, 0x30);
    /*			 (Bit 23-16)                                                                          */
    I2cWrite8bitDeviceRegister(0x1D, 0x0C);
    /*			 (Bit 15-8)                                                                           */
    I2cWrite8bitDeviceRegister(0x1E, 0x01);
    /*			 (Bit 7-0)                                                                            */
    I2cWrite8bitDeviceRegister(0x1F, 0x00);
    /*			 (Bit 31-24) ------------ MSB DAC INST No. 6                                          */
    I2cWrite8bitDeviceRegister(0x20, 0x30);
    /*			 (Bit 23-16)                                                                          */
    I2cWrite8bitDeviceRegister(0x21, 0x17);
    /*			 (Bit 15-8)                                                                           */
    I2cWrite8bitDeviceRegister(0x22, 0xFB);
    /*			 (Bit 7-0)                                                                            */
    I2cWrite8bitDeviceRegister(0x23, 0x00);
    /*			 (Bit 31-24) ------------ MSB DAC INST No. 7                                          */
    I2cWrite8bitDeviceRegister(0x24, 0x20);
    /*			 (Bit 23-16)                                                                          */
    I2cWrite8bitDeviceRegister(0x25, 0x04);
    /*			 (Bit 15-8)                                                                           */
    I2cWrite8bitDeviceRegister(0x26, 0x02);
    /*			 (Bit 7-0)                                                                            */
    I2cWrite8bitDeviceRegister(0x27, 0x00);
    /*			 (Bit 31-24) ------------ MSB DAC INST No. 8                                          */
    I2cWrite8bitDeviceRegister(0x28, 0x20);
    /*			 (Bit 23-16)                                                                          */
    I2cWrite8bitDeviceRegister(0x29, 0x04);
    /*			 (Bit 15-8)                                                                           */
    I2cWrite8bitDeviceRegister(0x2A, 0x03);
    /*			 (Bit 7-0)                                                                            */
    I2cWrite8bitDeviceRegister(0x2B, 0x00);
    /*			 (Bit 31-24) ------------ MSB DAC INST No. 9                                          */
    I2cWrite8bitDeviceRegister(0x2C, 0x20);
    /*			 (Bit 23-16)                                                                          */
    I2cWrite8bitDeviceRegister(0x2D, 0x04);
    /*			 (Bit 15-8)                                                                           */
    I2cWrite8bitDeviceRegister(0x2E, 0x04);
    /*			 (Bit 7-0)                                                                            */
    I2cWrite8bitDeviceRegister(0x2F, 0x00);
    /*			 (Bit 31-24) ------------ MSB DAC INST No. 10                                         */
    I2cWrite8bitDeviceRegister(0x30, 0x30);
    /*			 (Bit 23-16)                                                                          */
    I2cWrite8bitDeviceRegister(0x31, 0x43);
    /*			 (Bit 15-8)                                                                           */
    I2cWrite8bitDeviceRegister(0x32, 0xFB);
    /*			 (Bit 7-0)                                                                            */
    I2cWrite8bitDeviceRegister(0x33, 0x00);
    /*			 (Bit 31-24) ------------ MSB DAC INST No. 11                                         */
    I2cWrite8bitDeviceRegister(0x34, 0x38);
    /*			 (Bit 23-16)                                                                          */
    I2cWrite8bitDeviceRegister(0x35, 0x07);
    /*			 (Bit 15-8)                                                                           */
    I2cWrite8bitDeviceRegister(0x36, 0xFB);
    /*			 (Bit 7-0)                                                                            */
    I2cWrite8bitDeviceRegister(0x37, 0x00);
    /*			 (Bit 31-24) ------------ MSB DAC INST No. 12                                         */
    I2cWrite8bitDeviceRegister(0x38, 0x20);
    /*			 (Bit 23-16)                                                                          */
    I2cWrite8bitDeviceRegister(0x39, 0x04);
    /*			 (Bit 15-8)                                                                           */
    I2cWrite8bitDeviceRegister(0x3A, 0x05);
    /*			 (Bit 7-0)                                                                            */
    I2cWrite8bitDeviceRegister(0x3B, 0x00);
    /*			 (Bit 31-24) ------------ MSB DAC INST No. 13                                         */
    I2cWrite8bitDeviceRegister(0x3C, 0x48);
    /*			 (Bit 23-16)                                                                          */
    I2cWrite8bitDeviceRegister(0x3D, 0x0C);
    /*			 (Bit 15-8)                                                                           */
    I2cWrite8bitDeviceRegister(0x3E, 0x0F);
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
int main(void) {
    MAIN_DEBUG (("Main [%s]\n",__TIME__));

    /* certain chips require a HUB attach to enumerate as a USB device. */
    usbAttachToHub();

    /* initialise Sink Ahi */
    sinkAhiInit(&theSink.task);

    /* initialise memory required early */
    configManagerInitMemory();

    /* initialise device state */
    AuthResetConfirmationFlags();

    /* the internal regs must be latched on (smps and LDO)*/
    PioSetPowerPin(TRUE);

    switch (BootGetMode()) {
        #ifdef CVC_PRODTEST
        case BOOTMODE_CVC_PRODTEST:
            /* run the cvc prod test code and dont start the applicaiton */
            cvcProductionTestEnter();
        break;
        #endif
        case BOOTMODE_DFU:
            /* do nothing special for the DFU boot mode, this mode expects to have the appropriate host interface enabled. don't start the application */
            /* initializing only the system components required for flashing the led pattern in the DFU mode */

            configManagerInit(FALSE);
            LedManagerIndicateEvent(EventUsrEnterDFUMode);
        break;

        case BOOTMODE_DEFAULT:
        case BOOTMODE_CUSTOM:
        case BOOTMODE_USB_LOW_POWER:
        case BOOTMODE_ALT_FSTAB:
        default: {
            /* initialize global data for audio*/
            sinkAudioInit();
            sinkA2dpTtpLatencyInit();

            /* make sure the mute states are correctly set up */
            VolumeSetInitialMuteState();

            if (sinkAhiGetAppMode() == ahi_app_mode_configuration) {
                /* config mode - do not initialise the main sink app. */
                stateManagerEnterConfigMode();
                
                /* software reset (shutdown) for AIC3254 */
                Aic3254Shutdown();
            }
            else {
                /* configure Broadcast Audio mode based on last stored configuration */
                sinkBroadcastAudioConfigure();
                /* initialise the Connection lib */
                sinkConnectionInit();
            }
        }
        break;
    }

    /* initialise the Upgrade lib only if BA mode is not Active*/
    sinkUpgradeInit(&theSink.task);

    /* start protection mechanism for buffer defences */
    watchdogReset();

    /* start the message scheduler loop */
    MessageLoop();

    /* never get here... */
    return 0;
}

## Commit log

2020-12-09 Initial Release Source
    [SMT-PBTS(Altium).pcbdoc]
2020-12-09 Covers the software aspects of this repository (Schematics, PCB Source, PCB Gerber)
2020-12-09 Licenses
    Covers the software aspects of this repository (Schematic, PCB Source, PCB Gerber, etc.)
2020-12-09 Licenses
    Covers the hardware aspects and some images in this repository (Enclosure design of the speaker, overall design of the speaker, and images that contain the speaker)
2023-03-14 Assembled photo

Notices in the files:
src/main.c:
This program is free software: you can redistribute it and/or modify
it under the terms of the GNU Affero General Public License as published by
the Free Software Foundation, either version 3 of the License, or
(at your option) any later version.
